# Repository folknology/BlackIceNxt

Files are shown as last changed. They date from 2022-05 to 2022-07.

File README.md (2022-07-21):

# BlackIceNxt
BlackIce Nxt is a new systems board for the myStorm FPGA development board family. It sports the following features:
* STM32F730 216Mhz Arm Cortex 7 Microcontroller with 256K RAM, 64k Flash
* 64Mbit HypeRam, 128Mbit HyperFlash for the [MidPlane](https://github.com/folknology/IceLogicBus)
* 16Mbit SPI Flash for local storage
* 25Mhz HSE and 32.768Khz LSE crystals
* 40 Pin FMC Parallel interface expansion
* QSPI interface to [MidPlane](https://github.com/folknology/IceLogicBus)
* 4 Micro Blade sockets
* SDCard Socket
* SWD connector
* USB-C connector with serial over usb interface
* RGB Status LED and Mode button

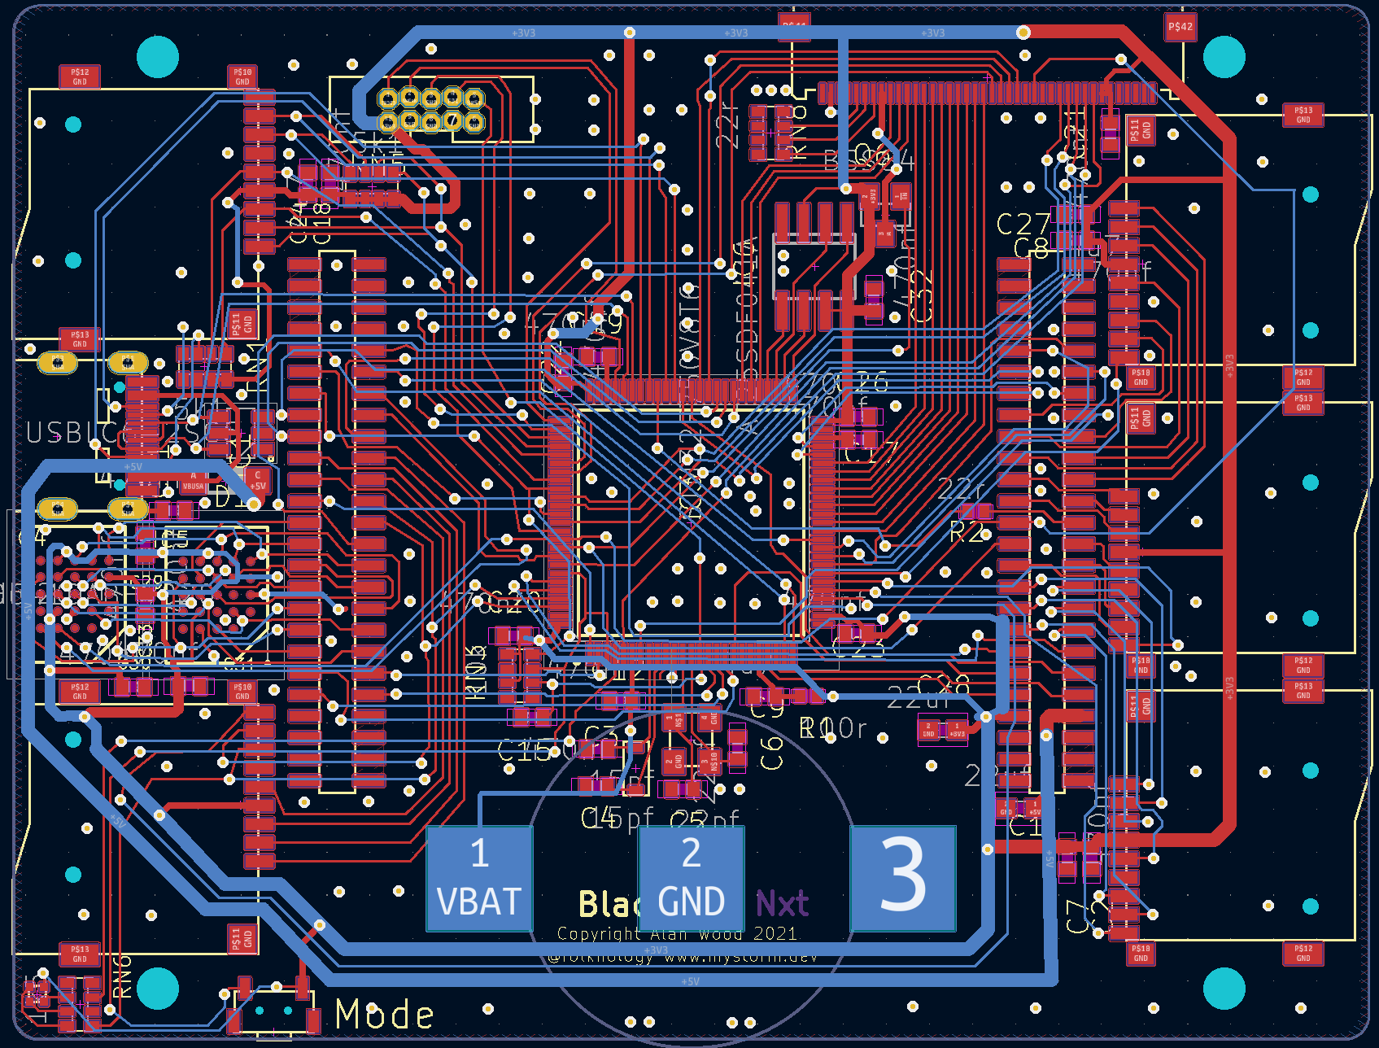
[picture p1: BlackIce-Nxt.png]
BlackIce

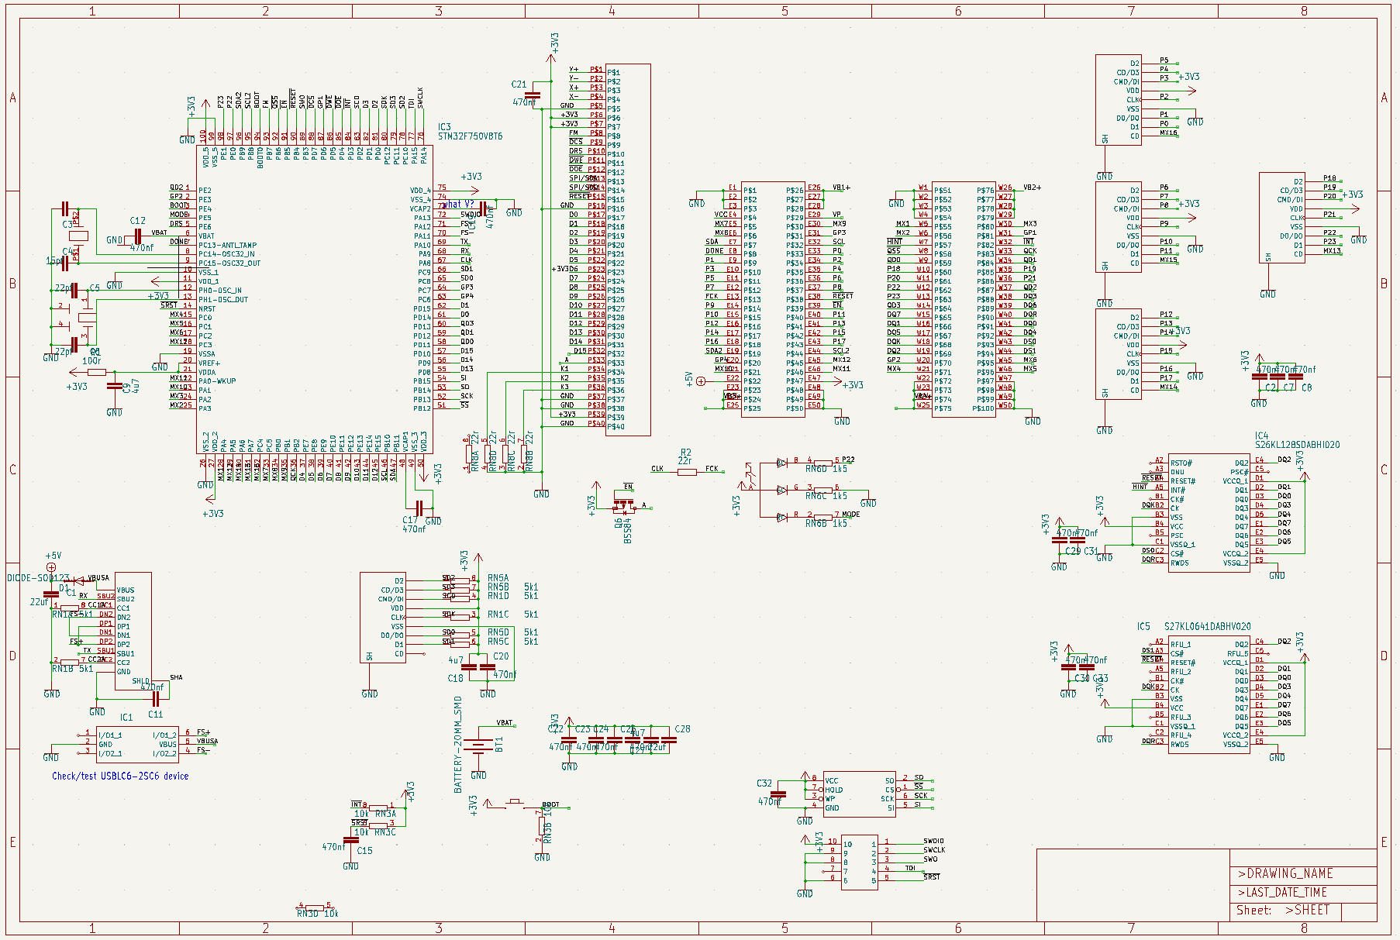
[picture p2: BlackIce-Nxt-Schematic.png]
BlackIce


### BlackIce Nxt PCB
BlackIce
### Top
BlackIce
### Bottom
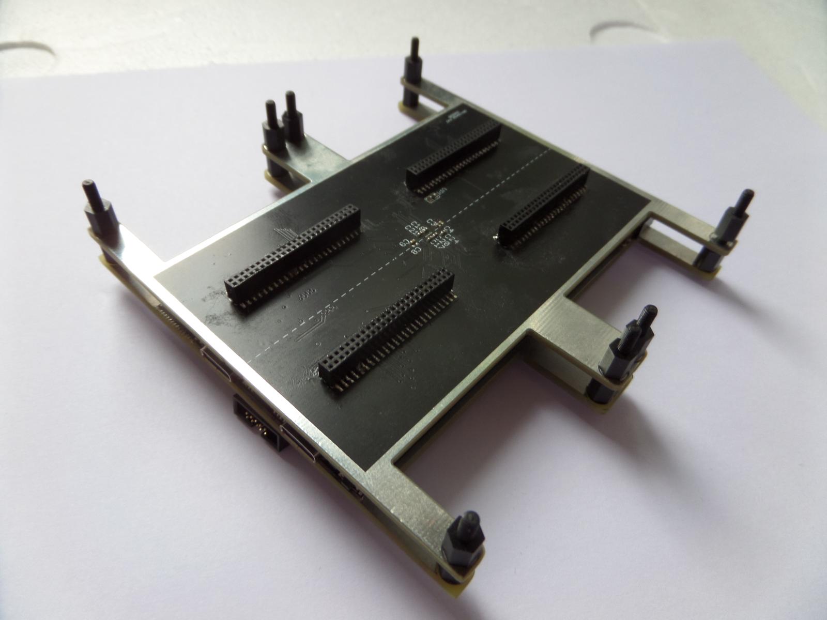
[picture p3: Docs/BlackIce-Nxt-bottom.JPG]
BlackIce


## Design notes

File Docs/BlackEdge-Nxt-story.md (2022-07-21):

# BlackEdge Nxt
* Where did this come from, some history a PCB Tour? 
* What are the key elements, what is being solved?
* Where does this lead & when can we play with it?

## BlackEdge History
### 2016 BlackIce II
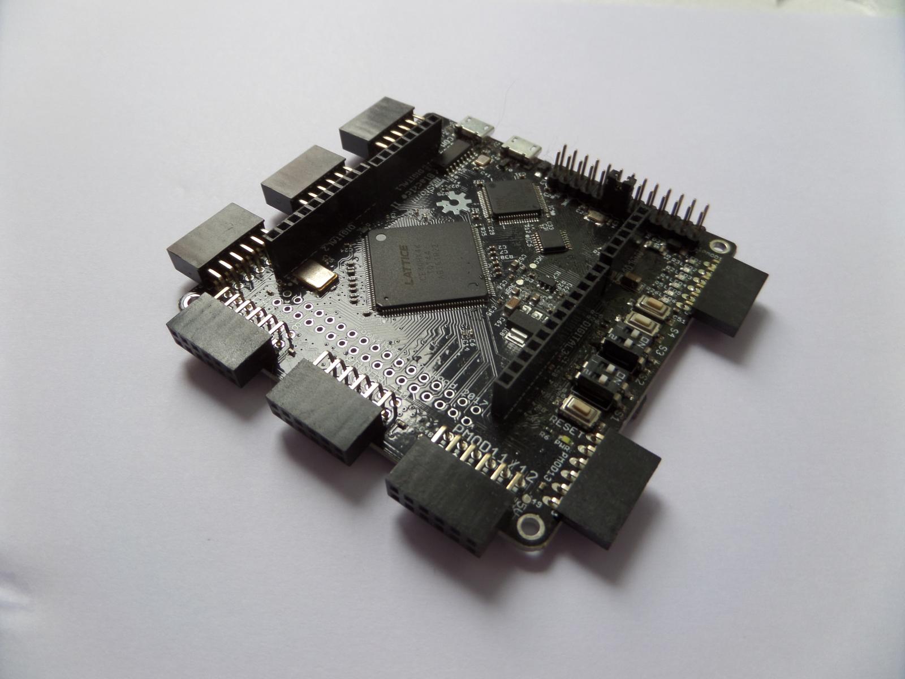
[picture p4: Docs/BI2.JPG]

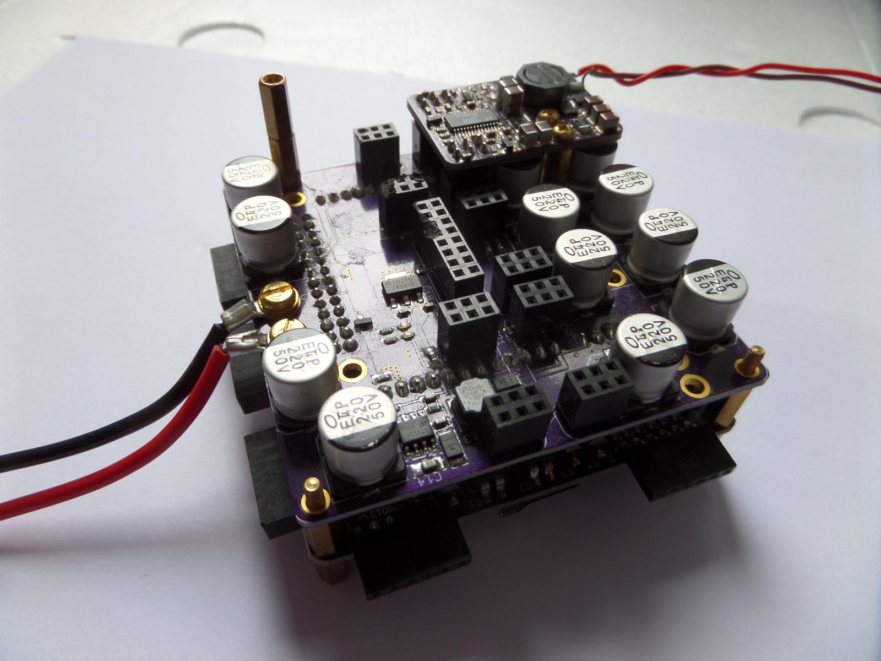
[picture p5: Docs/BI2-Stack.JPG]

### 2018 BlackIce MX
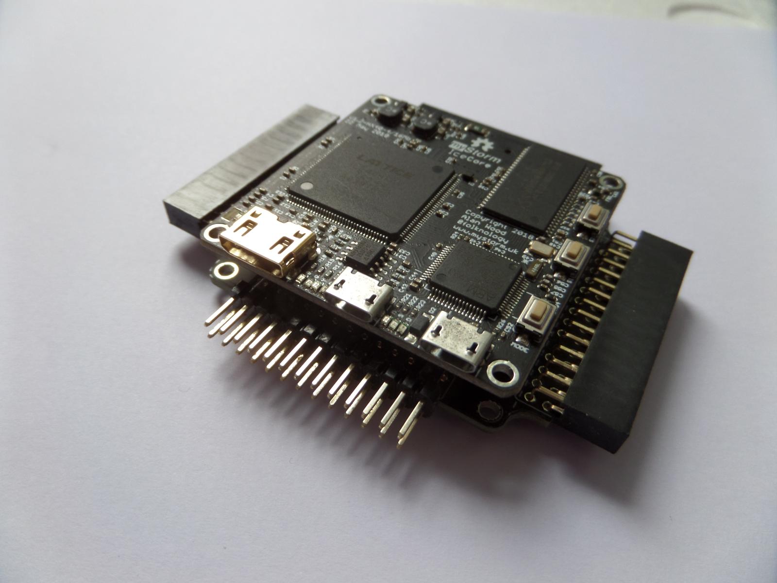
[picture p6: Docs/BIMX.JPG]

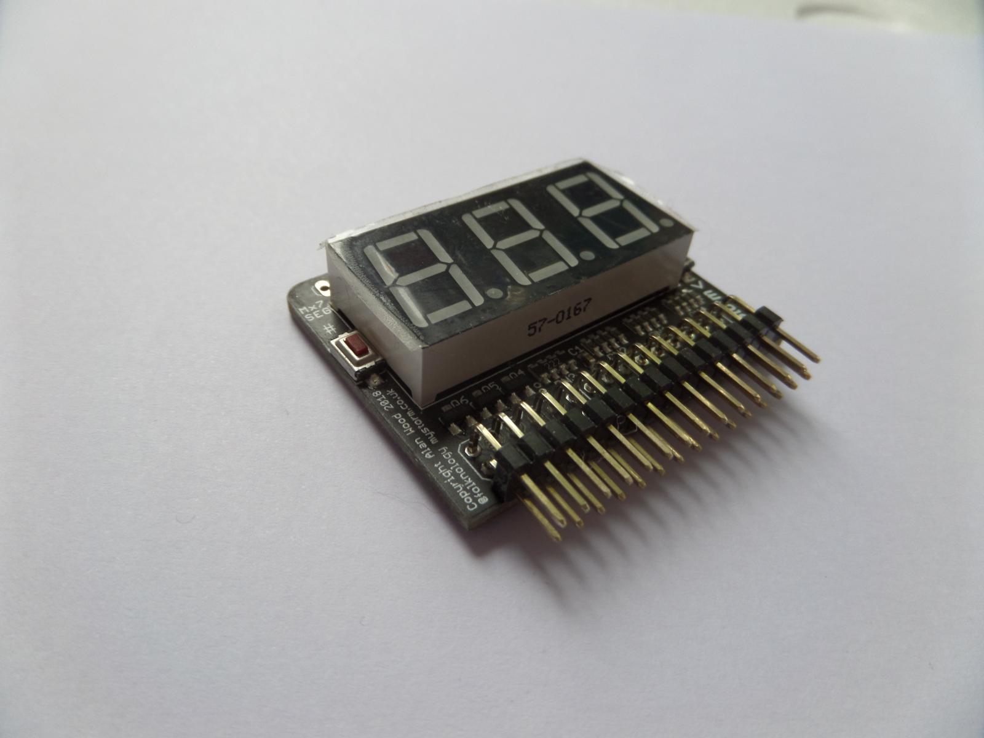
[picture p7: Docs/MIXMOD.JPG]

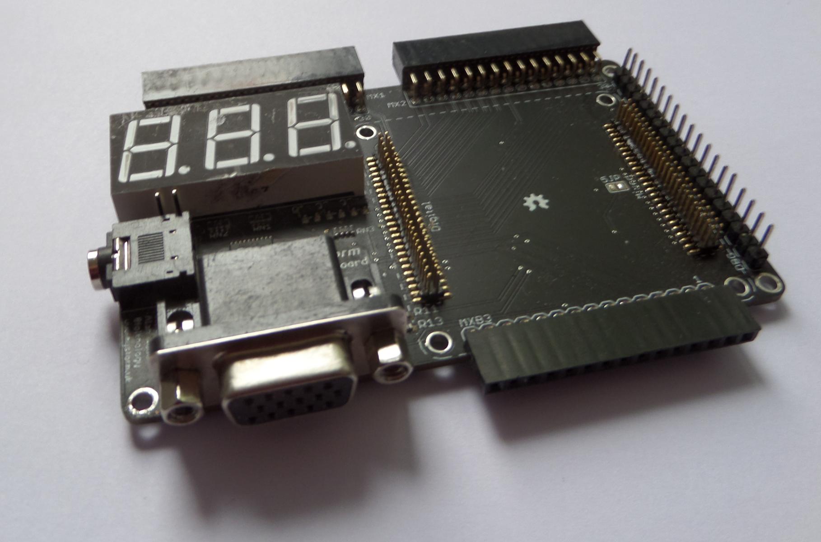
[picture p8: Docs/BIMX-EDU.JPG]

### 2019 Tiles & BlackEdge
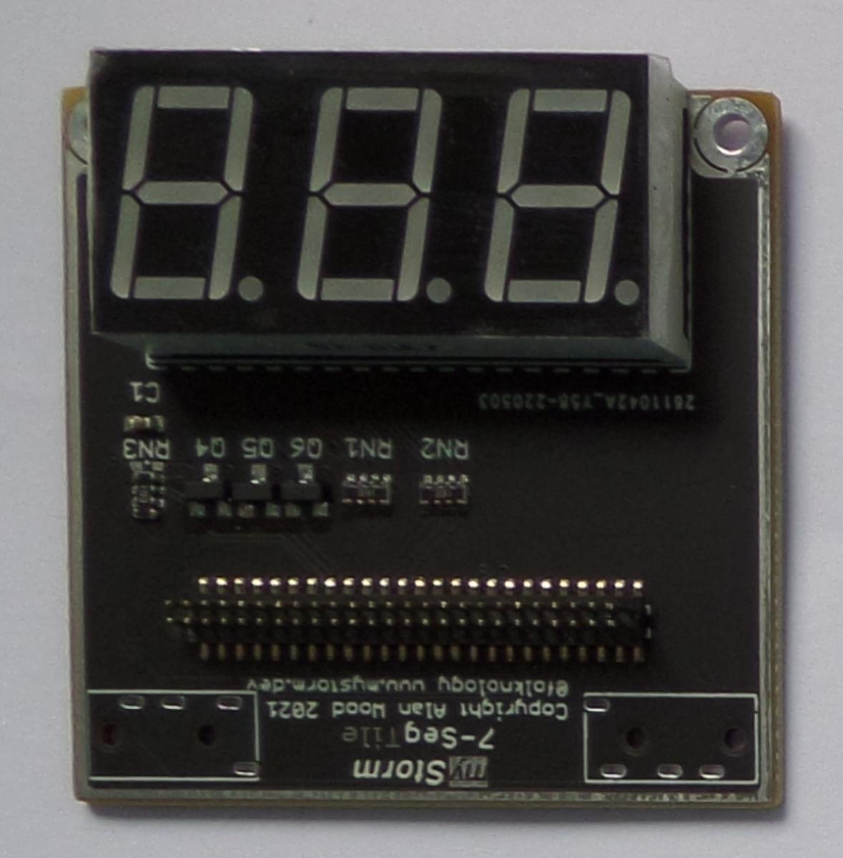
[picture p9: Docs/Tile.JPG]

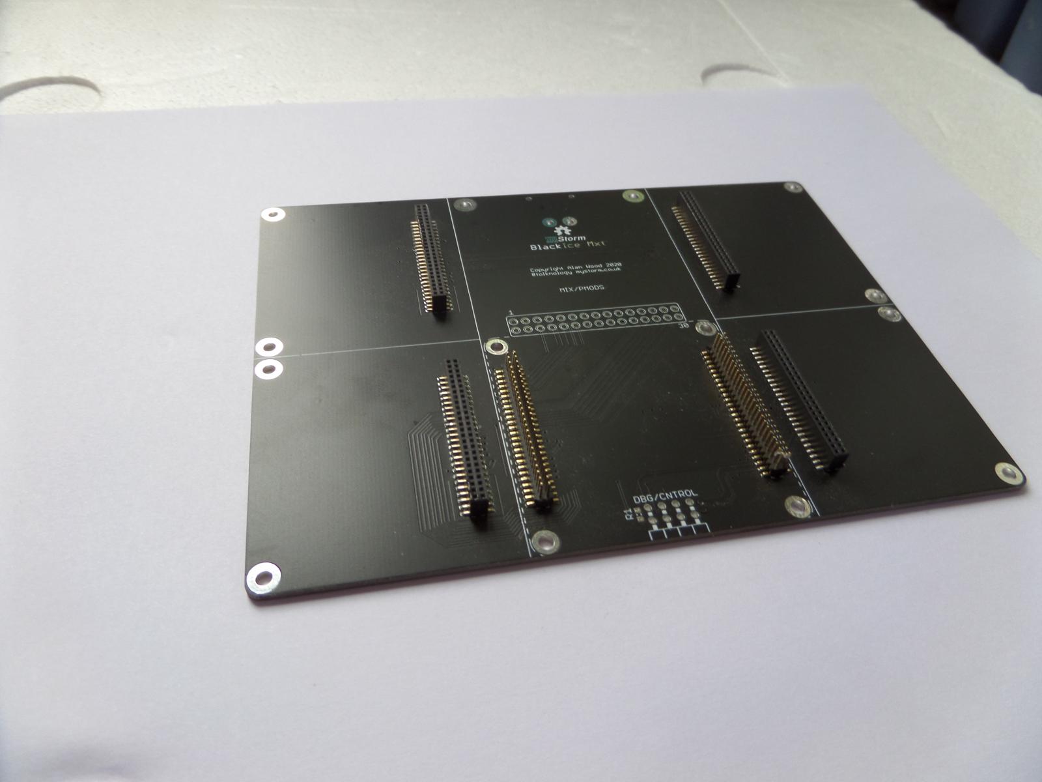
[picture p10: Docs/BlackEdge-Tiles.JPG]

### 2020 Tiles, IceLogicDeck + Mezzanine
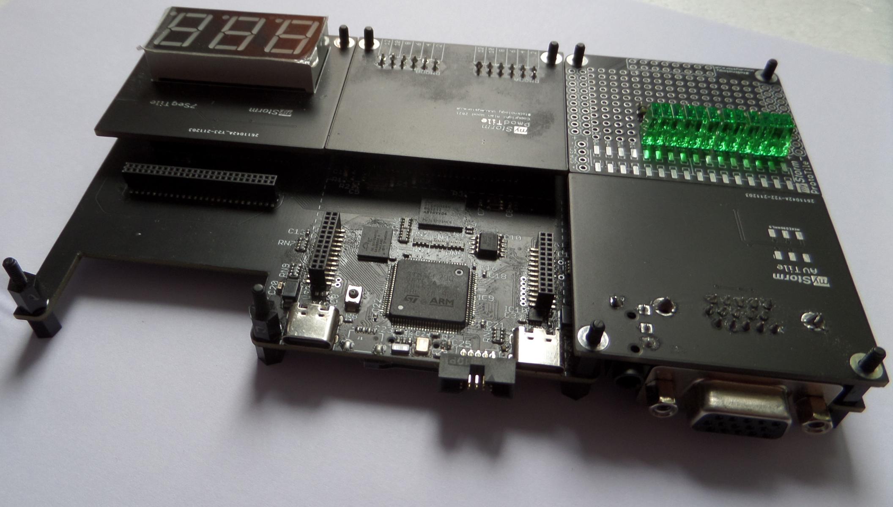
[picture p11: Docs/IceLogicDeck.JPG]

### 2021 Tiles, IceLogicDeck + BlackIce Nxt 
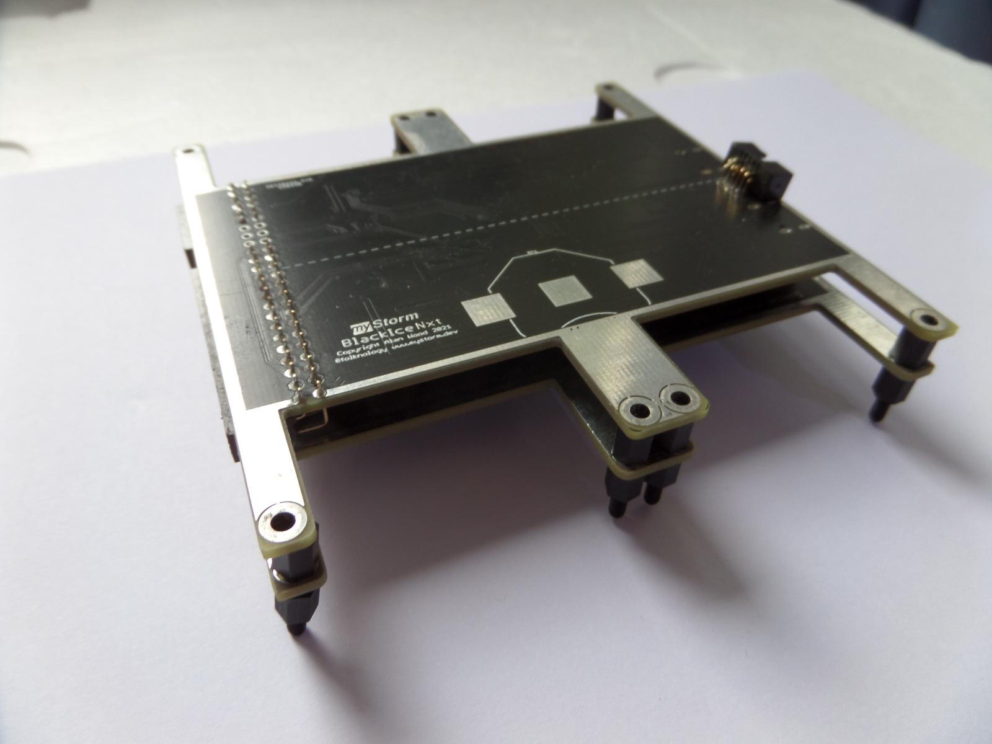
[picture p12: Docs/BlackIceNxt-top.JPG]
BlackIce

BlackIce
### 2022 Tiles, BlackEdge Nxt 
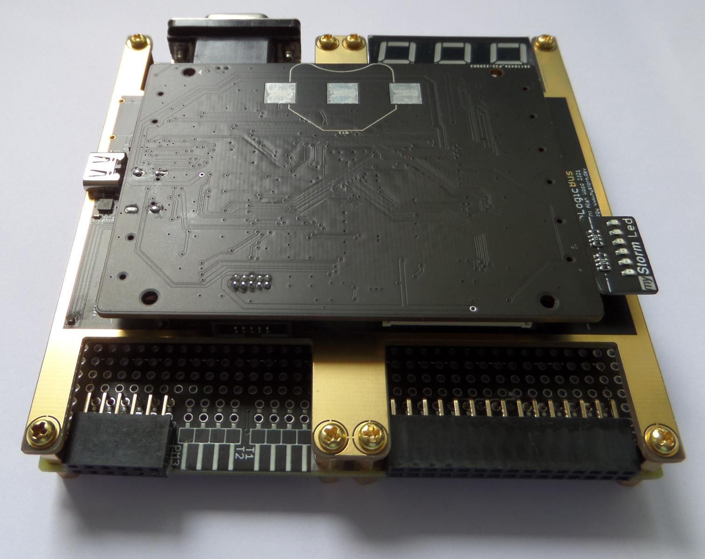
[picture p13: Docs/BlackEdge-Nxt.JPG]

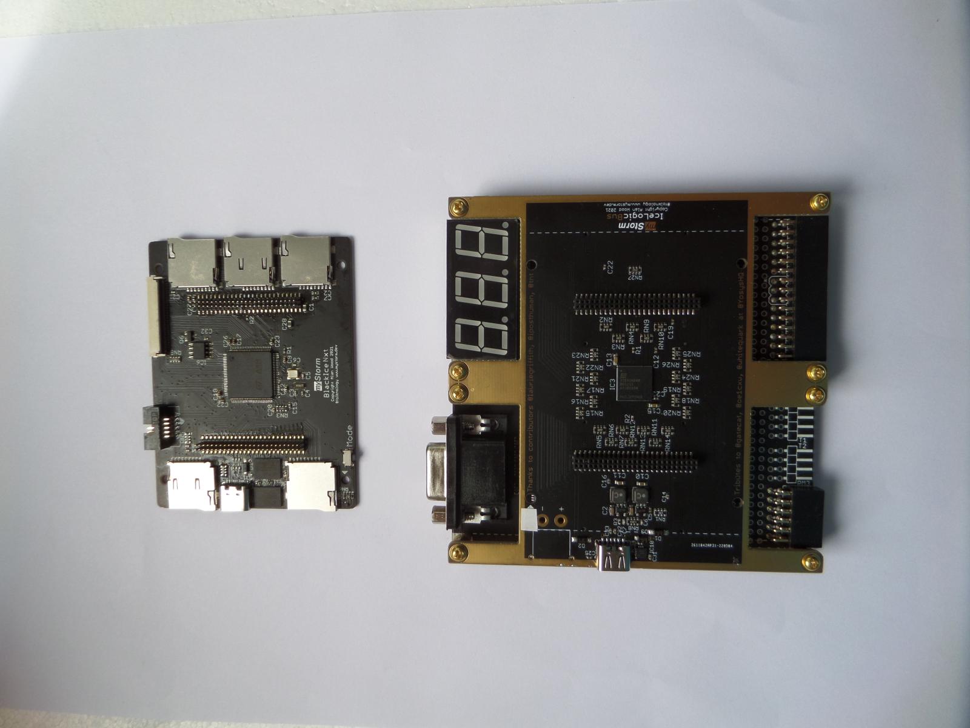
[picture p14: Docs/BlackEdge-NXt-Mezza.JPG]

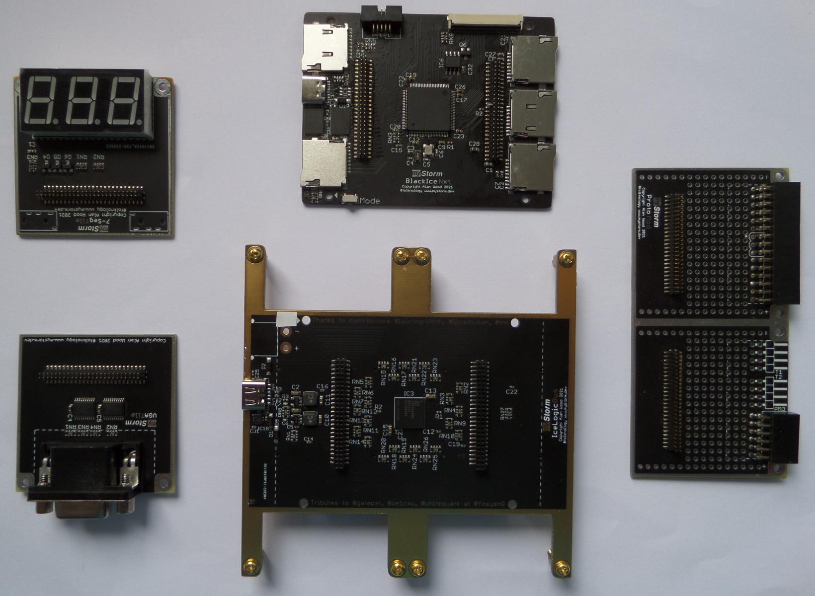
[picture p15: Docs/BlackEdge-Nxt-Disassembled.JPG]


## BlackEdge NXT Key Features
* Mechanical stability & robust and reliable
* Stacked physical 3D integration with headroom for connectivity
* Connectivity 12 FPGA Digital, 2 Mixed signal, High Power and control.
* Interchangeable BlackEdge Nxt Controller
* Complete Compact modularity with Software/Tools

# [BlackEdge NXT https://github.com/folknology/BlackIceNxt/](https://github.com/folknology/BlackIceNxt/)

# [Discord https://discord.gg/SwexczKsqm](https://discord.gg/SwexczKsqm)

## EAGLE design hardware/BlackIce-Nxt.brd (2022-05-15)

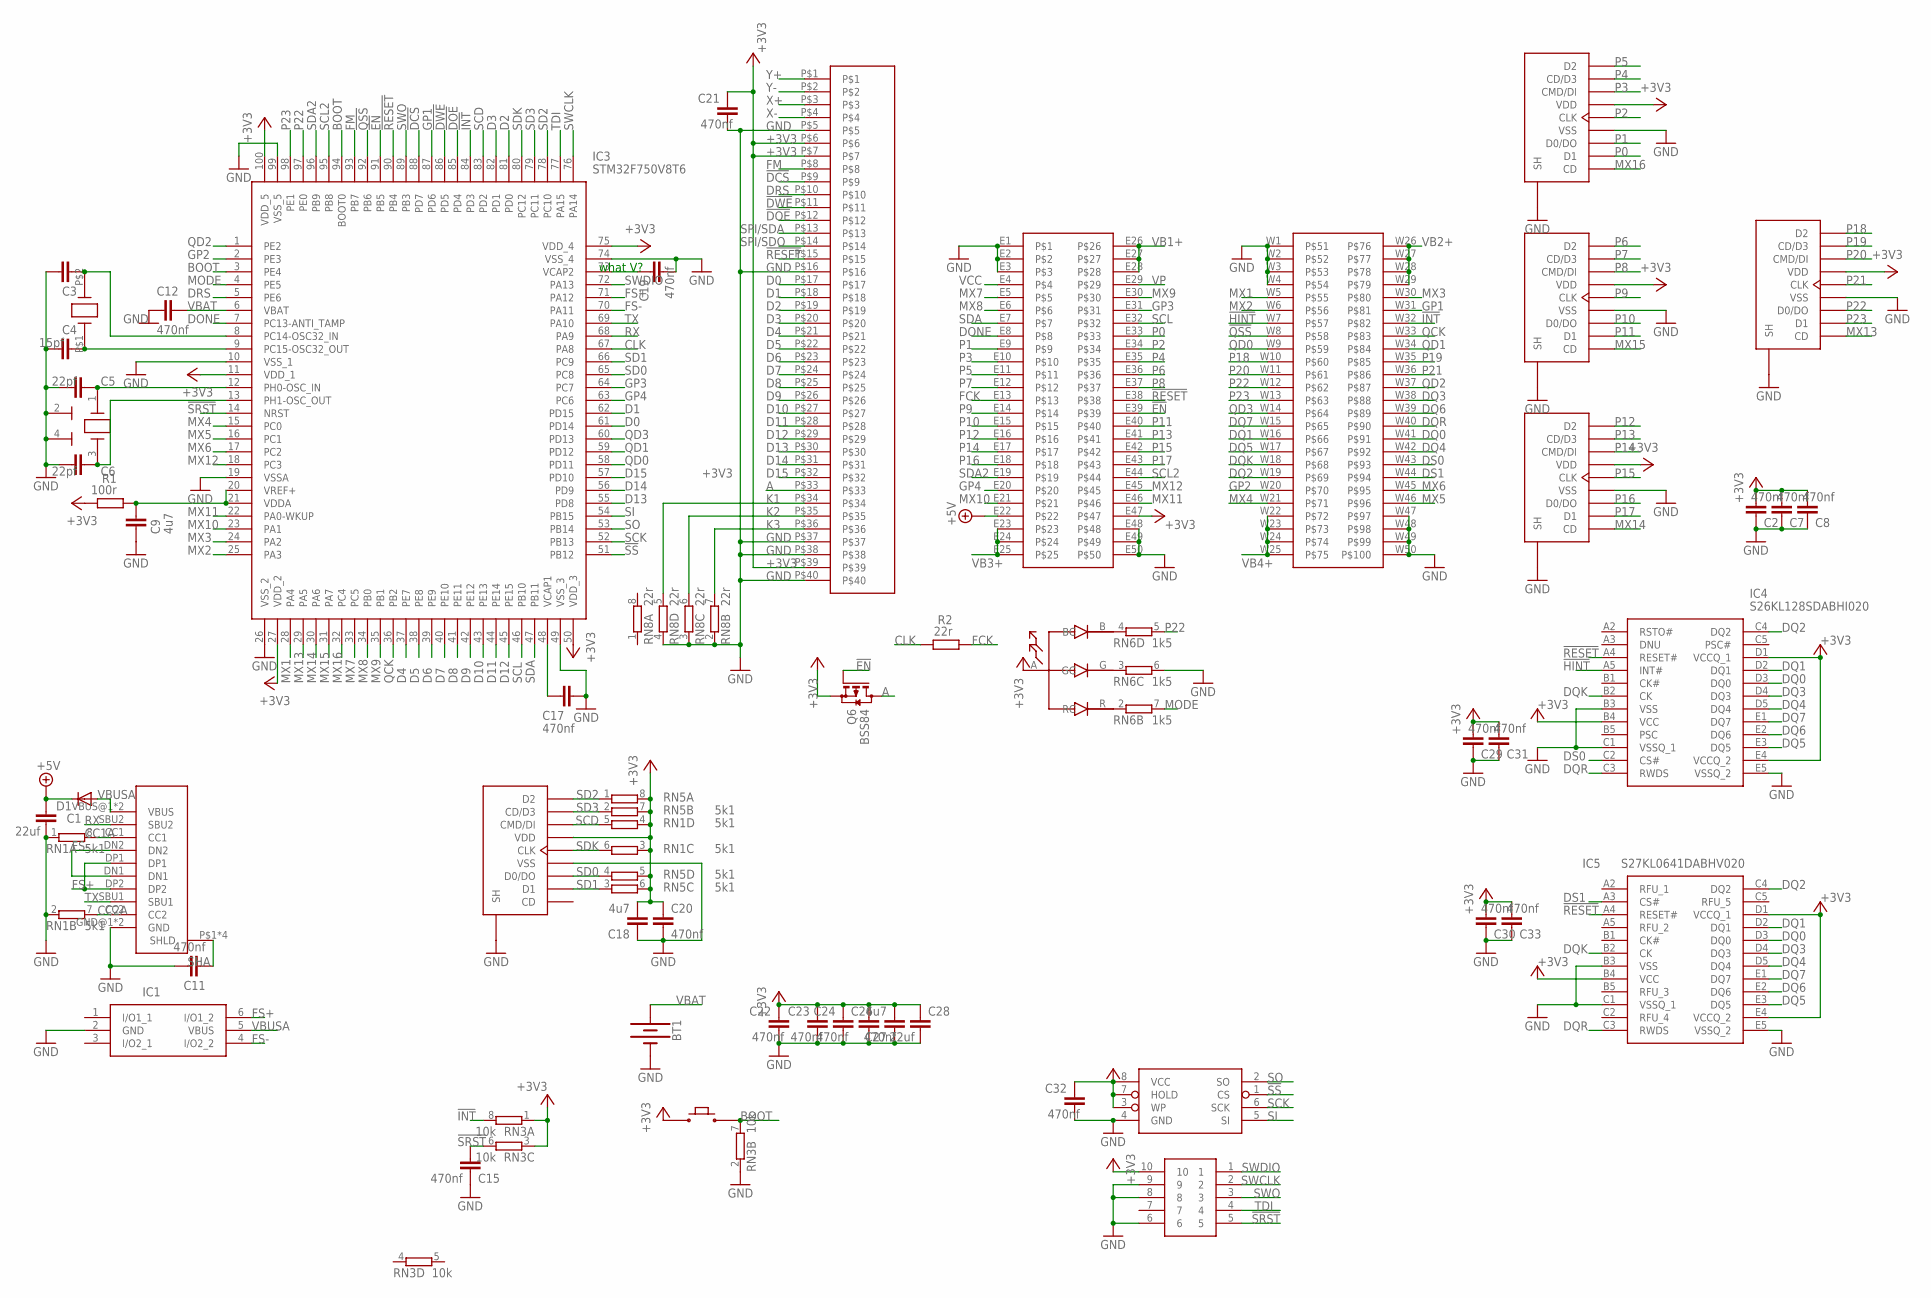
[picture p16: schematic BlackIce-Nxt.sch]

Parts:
B2: 4X3-RA-BUTTON
BT1: BATTERY-20MM_SMD; BATTCON_20MM
C1, C28: 22uf; C0603
C2, C7, C8, C11, C12, C15, C17, C19, C20, C21, C22, C23, C24, C26, C29, C30, C31, C32, C33: 470nf; C0402
C3, C4: 15pf; C0402
C5, C6: 22pf; C0402
C9, C18, C27: 4u7; C0402
C10: USB-C-16; USB-C
C16, C35, C36, C38, C41: TF-15X15; SDCARD
C25: XF2M-4015-1AFPC-0.5; XF2M-4015-1A
C34: 2X5-HEADER; 1.27-2X5-HEADER
D1: DIODE-SOD123; SOD123
IC1: USBLC6-2SC6; SOT95P280X145-6N
IC3: STM32F750V8T6; QFP50P1600X1600X160-100N
IC4: S26KL128SDABHI020; BGA24C100P5X5_600X800X100
IC5: S27KL0641DABHV020; BGA24C100P5X5_600X800X100
IC6: AT25SDF041A; SOIC-8-NARROW
L1: RGB_LED; RGB_LED_IMM
Q6: BSS84; SOT23
R1: 100r; R0402
R2: 22r; R0402
RN1, RN5: 5k1; EXB38V
RN3: 10k; EXB38V
RN6: 1k5; EXB38V
RN8: 22r; EXB38V
T1: MEZZANINEM-TILE; MEZZANINNE-T
X1: FC-135; FC135
X2: 12MZ; CRYSTAL-3.2X2.5

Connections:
!DCS: C25.P$9, IC3.88 (PD7)
!DOE: C25.P$12, IC3.85 (PD4)
!DWE: C25.P$11, IC3.86 (PD5)
!EN: IC3.91 (PB5), Q6.1 (G), T1.E39
!HINT: IC4.A5 (INT#), T1.W7
!INT: IC3.84 (PD3), RN3.8 (2), T1.W32
!QSS: IC3.92 (PB6), T1.W8
!RESET: C25.P$15, IC3.90 (PB4), IC4.A4 (RESET#), IC5.A4 (RESET#), T1.E38
!SRST: C15.2, C34.5, IC3.14 (NRST), RN3.6 (2)
!SS: IC3.51 (PB12), IC6.1 (CS)
+3V3: B2.P$1, C2.2, C7.2, C8.2, C16.P$6 (VDD), C18.2, C20.1, C21.1, C22.1, C23.1, C24.1, C25.P$6, C25.P$7, C25.P$39, C26.2, C27.2, C28.1, C29.2, C30.2, C31.2, C32.1, C33.2, C34.10, C35.P$6 (VDD), C36.P$6 (VDD), C38.P$6 (VDD), C41.P$6 (VDD), IC3.11 (VDD_1), IC3.27 (VDD_2), IC3.50 (VDD_3), IC3.75 (VDD_4), IC3.100 (VDD_5), IC4.B4 (VCC), IC4.D1 (VCCQ_1), IC4.E4 (VCCQ_2), IC5.B4 (VCC), IC5.D1 (VCCQ_1), IC5.E4 (VCCQ_2), IC6.3 (WP), IC6.7 (HOLD), IC6.8 (VCC), L1.A (ANODE), Q6.2 (S), R1.2, RN1.3 (1), RN1.4 (1), RN3.1, RN3.3 (1), RN5.5 (2), RN5.6 (2), RN5.7 (2), RN5.8 (2), T1.E47
+5V: C1.1, D1.C, T1.E22
A: C25.P$33, Q6.3 (D)
BOOT: B2.P$2, IC3.3 (PE4), IC3.94 (BOOT0), RN3.7 (2)
CC1A: C10.CC1, RN1.8 (2)
CC2A: C10.CC2, RN1.7 (2)
CLK: IC3.67 (PA8), R2.2
D0: C25.P$17, IC3.61 (PD14)
D1: C25.P$18, IC3.62 (PD15)
D2: C25.P$19, IC3.81 (PD0)
D3: C25.P$20, IC3.82 (PD1)
D4: C25.P$21, IC3.37 (PE7)
D5: C25.P$22, IC3.38 (PE8)
D6: C25.P$23, IC3.39 (PE9)
D7: C25.P$24, IC3.40 (PE10)
D8: C25.P$25, IC3.41 (PE11)
D9: C25.P$26, IC3.42 (PE12)
D10: C25.P$27, IC3.43 (PE13)
D11: C25.P$28, IC3.44 (PE14)
D12: C25.P$29, IC3.45 (PE15)
D13: C25.P$30, IC3.55 (PD8)
D14: C25.P$31, IC3.56 (PD9)
D15: C25.P$32, IC3.57 (PD10)
DONE: IC3.7 (PC13-ANTI_TAMP), T1.E8
DQ0: IC4.D3 (DQ0), IC5.D3 (DQ0), T1.W41
DQ1: IC4.D2 (DQ1), IC5.D2 (DQ1), T1.W16
DQ2: IC4.C4 (DQ2), IC5.C4 (DQ2), T1.W19
DQ3: IC4.D4 (DQ3), IC5.D4 (DQ3), T1.W38
DQ4: IC4.D5 (DQ4), IC5.D5 (DQ4), T1.W42
DQ5: IC4.E3 (DQ5), IC5.E3 (DQ5), T1.W17
DQ6: IC4.E2 (DQ6), IC5.E2 (DQ6), T1.W39
DQ7: IC4.E1 (DQ7), IC5.E1 (DQ7), T1.W15
DQK: IC4.B2 (CK), IC5.B2 (CK), T1.W18
DQR: IC4.C3 (RWDS), IC5.C3 (RWDS), T1.W40
DRS: C25.P$10, IC3.5 (PE6)
DS0: IC4.C2 (CS#), T1.W43
DS1: IC5.A3 (CS#), T1.W44
FCK: R2.1, T1.E13
FM: C25.P$8, IC3.93 (PB7)
FS+: C10.DP1, C10.DP2, IC1.6 (I/O1_2), IC3.71 (PA12)
FS-: C10.DN1, C10.DN2, IC1.4 (I/O2_2), IC3.70 (PA11)
GND: BT1.2 (-), C1.2, C2.1, C3.1, C4.1, C5.1, C6.1, C7.1, C8.1, C9.2, C10.GND@1 (GND), C10.GND@2 (GND), C11.1, C12.2, C15.1, C16.P$4 (VSS), C16.P$10 (SH), C16.P$11 (SH), C16.P$12 (SH), C16.P$13 (SH), C17.1, C18.1, C19.2, C20.2, C21.2, C22.2, C23.2, C24.2, C25.P$5, C25.P$16, C25.P$37, C25.P$38, C25.P$40, C26.1, C27.1, C28.2, C29.1, C30.1, C31.1, C32.2, C33.1, C34.6, C34.8, C34.9, C35.P$4 (VSS), C35.P$10 (SH), C35.P$11 (SH), C35.P$12 (SH), C35.P$13 (SH), C36.P$4 (VSS), C36.P$10 (SH), C36.P$11 (SH), C36.P$12 (SH), C36.P$13 (SH), C38.P$4 (VSS), C38.P$10 (SH), C38.P$11 (SH), C38.P$12 (SH), C38.P$13 (SH), C41.P$4 (VSS), C41.P$10 (SH), C41.P$11 (SH), C41.P$12 (SH), C41.P$13 (SH), IC1.2 (GND), IC3.10 (VSS_1), IC3.19 (VSSA), IC3.26 (VSS_2), IC3.49 (VSS_3), IC3.74 (VSS_4), IC3.99 (VSS_5), IC4.B3 (VSS), IC4.C1 (VSSQ_1), IC4.E5 (VSSQ_2), IC5.B3 (VSS), IC5.C1 (VSSQ_1), IC5.E5 (VSSQ_2), IC6.4 (GND), RN1.1, RN1.2 (1), RN3.2 (1), RN6.6 (2), RN8.2 (1), RN8.3 (1), RN8.4 (1), T1.E1, T1.E2, T1.E3, T1.E48, T1.E49, T1.E50, T1.W1, T1.W2, T1.W3, T1.W4, T1.W47, T1.W48, T1.W49, T1.W50, X2.2 (GND), X2.4 (GND)
GP1: IC3.87 (PD6), T1.W31
GP2: IC3.2 (PE3), T1.W20
GP3: IC3.64 (PC7), T1.E31
GP4: IC3.63 (PC6), T1.E20
K1: C25.P$34, RN8.5 (2)
K2: C25.P$35, RN8.6 (2)
K3: C25.P$36, RN8.7 (2)
MODE: IC3.4 (PE5), RN6.7 (2)
MX1: IC3.28 (PA4), T1.W5
MX2: IC3.25 (PA3), T1.W6
MX3: IC3.24 (PA2), T1.W30
MX4: IC3.15 (PC0), T1.W21
MX5: IC3.16 (PC1), T1.W46
MX6: IC3.17 (PC2), T1.W45
MX7: IC3.33 (PC5), T1.E5
MX8: IC3.34 (PB0), T1.E6
MX9: IC3.35 (PB1), T1.E30
MX10: IC3.23 (PA1), T1.E21
MX11: IC3.22 (PA0-WKUP), T1.E46
MX12: IC3.18 (PC3), T1.E45
MX13: C41.P$1 (CD), IC3.29 (PA5)
MX14: C36.P$1 (CD), IC3.30 (PA6)
MX15: C38.P$1 (CD), IC3.31 (PA7)
MX16: C35.P$1 (CD), IC3.32 (PC4)
unnamed: L1.G (GC), RN6.3 (1)
unnamed: L1.R (RC), RN6.2 (1)
unnamed: L1.B (BC), RN6.4 (1)
unnamed: C6.2, IC3.13 (PH1-OSC_OUT), X2.3 (X2)
unnamed: C5.2, IC3.12 (PH0-OSC_IN), X2.1 (X1)
unnamed: C4.2, IC3.9 (PC15-OSC32_OUT), X1.P$1 (X1)
unnamed: C3.2, IC3.8 (PC14-OSC32_IN), X1.P$2 (X2)
unnamed: C19.1, IC3.73 (VCAP2)
unnamed: C17.2, IC3.48 (VCAP1)
unnamed: C9.1, IC3.20 (VREF+), IC3.21 (VDDA), R1.1
P0: C35.P$2 (D1), T1.E33
P1: C35.P$3 (D0/DO), T1.E9
P2: C35.P$5 (CLK), T1.E34
P3: C35.P$7 (CMD/DI), T1.E10
P4: C35.P$8 (CD/D3), T1.E35
P5: C35.P$9 (D2), T1.E11
P6: C38.P$9 (D2), T1.E36
P7: C38.P$8 (CD/D3), T1.E12
P8: C38.P$7 (CMD/DI), T1.E37
P9: C38.P$5 (CLK), T1.E14
P10: C38.P$3 (D0/DO), T1.E15
P11: C38.P$2 (D1), T1.E40
P12: C36.P$9 (D2), T1.E16
P13: C36.P$8 (CD/D3), T1.E41
P14: C36.P$7 (CMD/DI), T1.E17
P15: C36.P$5 (CLK), T1.E42
P16: C36.P$3 (D0/DO), T1.E18
P17: C36.P$2 (D1), T1.E43
P18: C41.P$9 (D2), T1.W10
P19: C41.P$8 (CD/D3), T1.W35
P20: C41.P$7 (CMD/DI), T1.W11
P21: C41.P$5 (CLK), T1.W36
P22: C41.P$3 (D0/DO), IC3.97 (PE0), RN6.5 (2), T1.W12
P23: C41.P$2 (D1), IC3.98 (PE1), T1.W13
QCK: IC3.36 (PB2), T1.W33
QD0: IC3.58 (PD11), T1.W9
QD1: IC3.59 (PD12), T1.W34
QD2: IC3.1 (PE2), T1.W37
QD3: IC3.60 (PD13), T1.W14
RX: C10.SBU2, IC3.68 (PA9)
SCD: C16.P$7 (CMD/DI), IC3.83 (PD2), RN1.5 (2)
SCK: IC3.52 (PB13), IC6.6 (SCK)
SCL: IC3.46 (PB10), T1.E32
SCL2: IC3.95 (PB8), T1.E44
SD0: C16.P$3 (D0/DO), IC3.65 (PC8), RN5.4 (1)
SD1: C16.P$2 (D1), IC3.66 (PC9), RN5.3 (1)
SD2: C16.P$9 (D2), IC3.78 (PC10), RN5.1
SD3: C16.P$8 (CD/D3), IC3.79 (PC11), RN5.2 (1)
SDA: IC3.47 (PB11), T1.E7
SDA2: IC3.96 (PB9), T1.E19
SDK: C16.P$5 (CLK), IC3.80 (PC12), RN1.6 (2)
SHA: C10.P$1 (SHLD), C10.P$2 (SHLD), C10.P$3 (SHLD), C10.P$4 (SHLD), C11.2
SI: IC3.54 (PB15), IC6.5 (SI)
SO: IC3.53 (PB14), IC6.2 (SO)
SPI/SDA: C25.P$13
SPI/SDO: C25.P$14
SWCLK: C34.2, IC3.76 (PA14)
SWDIO: C34.1, IC3.72 (PA13)
SWO: C34.3, IC3.89 (PB3)
TDI: C34.4, IC3.77 (PA15)
TX: C10.SBU1, IC3.69 (PA10)
VB1+: T1.E26, T1.E27, T1.E28
VB2+: T1.W26, T1.W27, T1.W28, T1.W29
VB3+: T1.E23, T1.E24, T1.E25
VB4+: T1.W22, T1.W23, T1.W24, T1.W25
VBAT: BT1.1 (+), C12.1, IC3.6 (VBAT)
VBUSA: C10.VBUS@1 (VBUS), C10.VBUS@2 (VBUS), D1.A, IC1.5 (VBUS)
VCC: T1.E4
VP: T1.E29
X+: C25.P$3
X-: C25.P$4
Y+: C25.P$1
Y-: C25.P$2

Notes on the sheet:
what V?

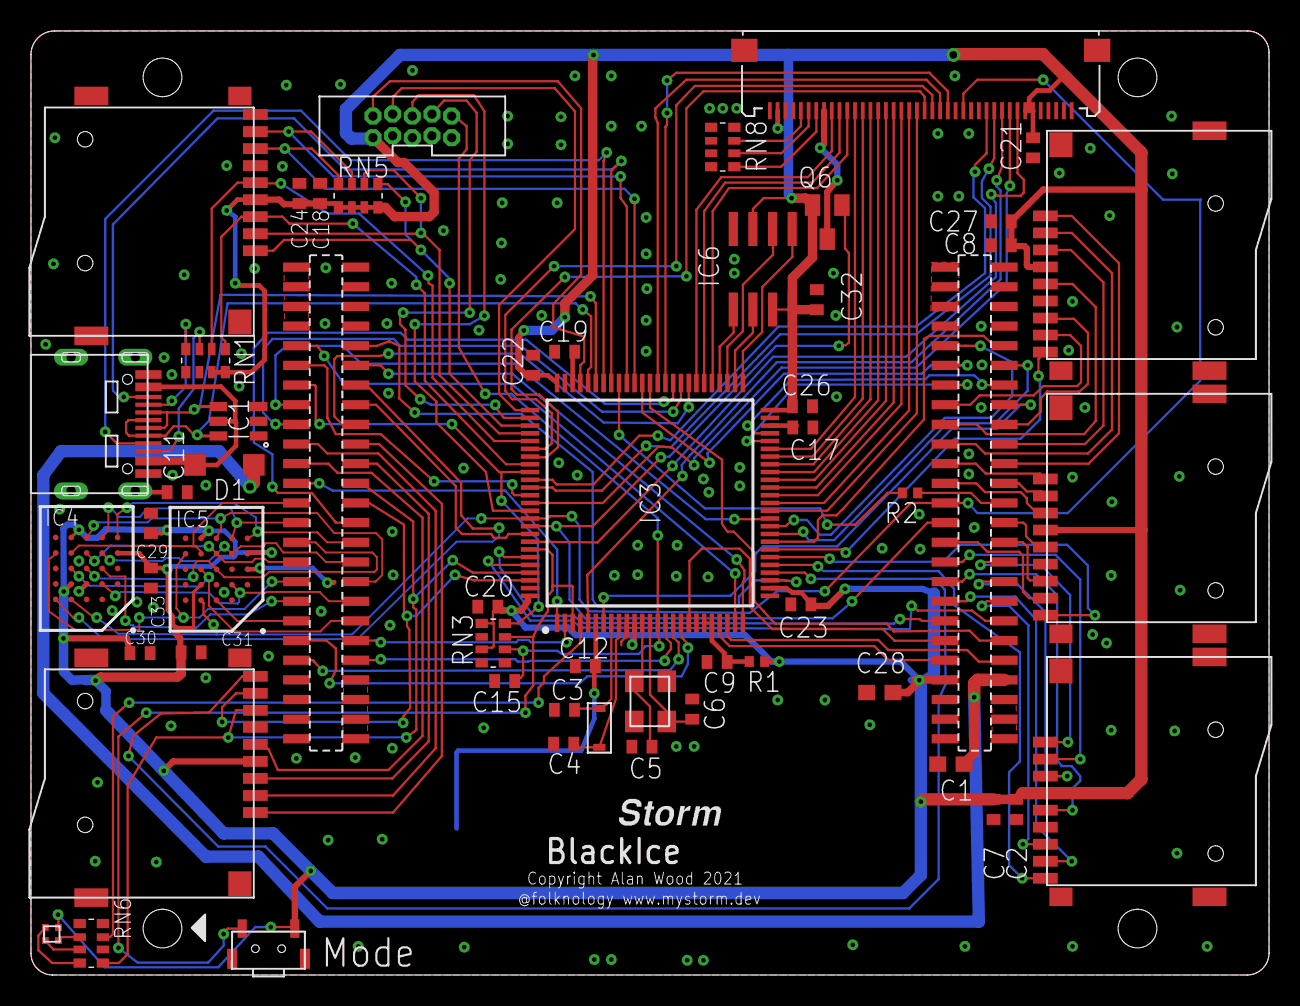
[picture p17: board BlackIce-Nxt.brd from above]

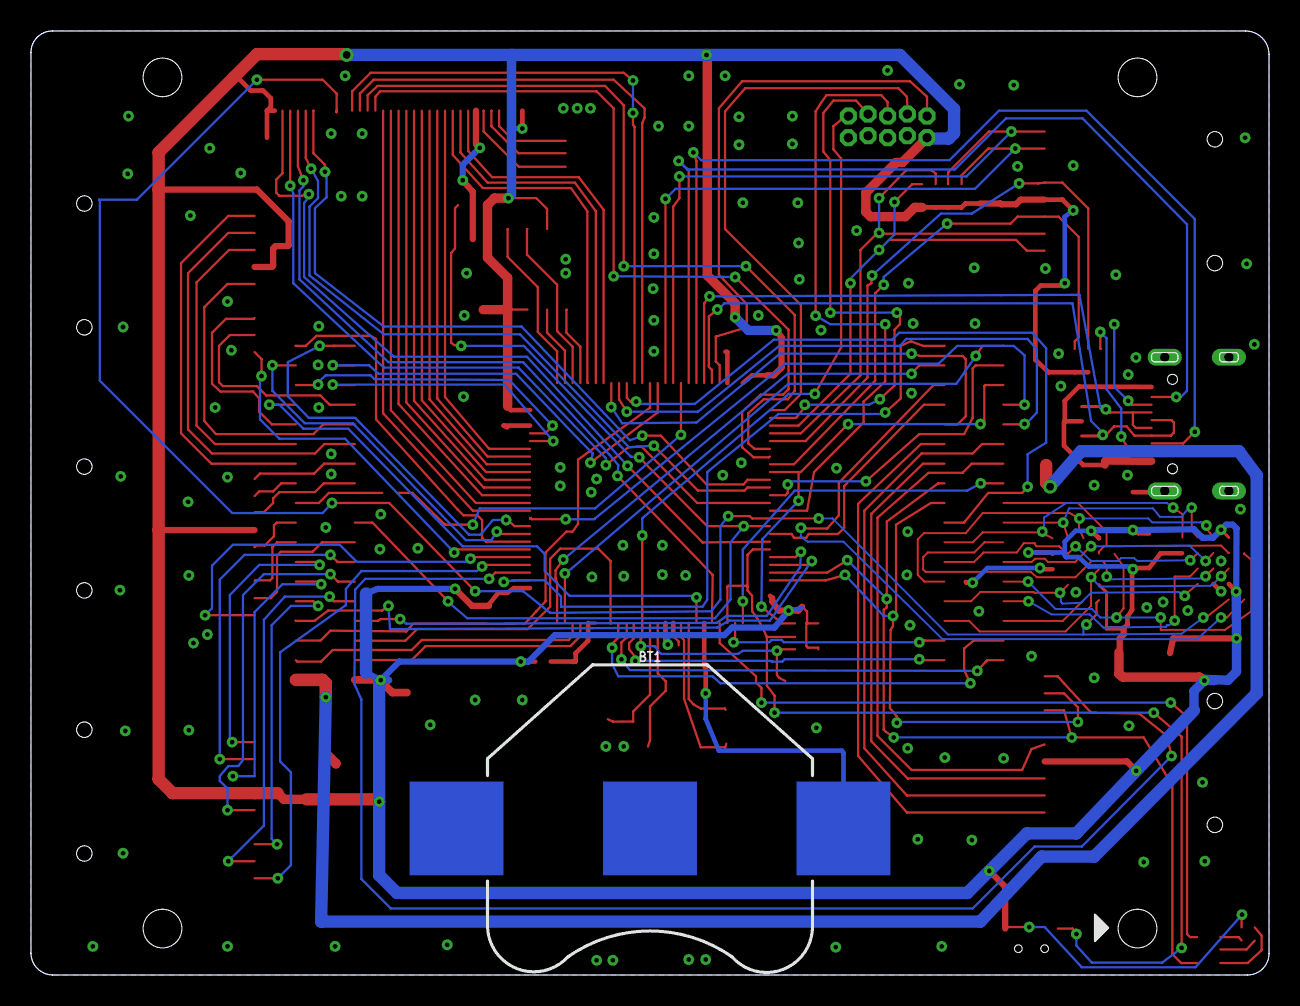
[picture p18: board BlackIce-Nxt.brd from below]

Board: 2 copper layers, 80.0 x 61.0 mm, 56 parts (3 on the bottom side), 141 nets.

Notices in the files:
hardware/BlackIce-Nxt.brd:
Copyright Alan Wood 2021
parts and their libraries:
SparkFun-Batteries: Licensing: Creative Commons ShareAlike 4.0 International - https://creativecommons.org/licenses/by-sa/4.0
